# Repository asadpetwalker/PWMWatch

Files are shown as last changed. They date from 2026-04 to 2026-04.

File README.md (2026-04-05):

# PWMWatch
# What My Project Is
My project is a watch using the CrystalFontz CFAL12856A0 transparent display, the STM32WB50CGU5 mcu, and the RV3028-C7 RTC.

# Why I made my project
The electronics of watches are like really cool, and I don't see anyone actually talking about them more. I smashed a broken smart watch with a hammer, and inside there was a bunch of electronics that were really cool when I desoldered them. Additionally, the display I found, the CrystalFontz CFAL12856A0 is really cool, and I wanted to combine these two things to make a really cool watch that also focuses on the electronics.

# Pictures

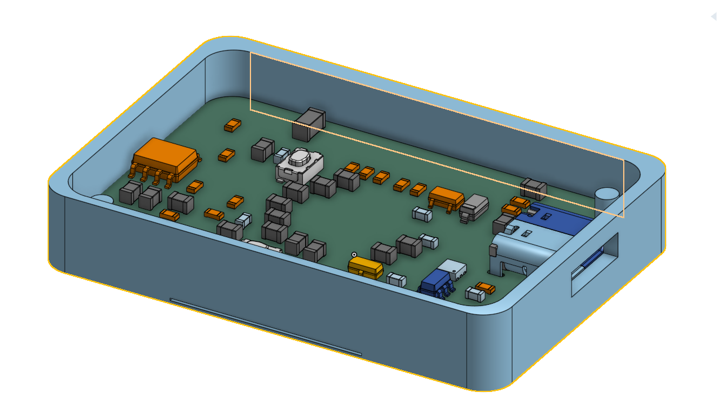
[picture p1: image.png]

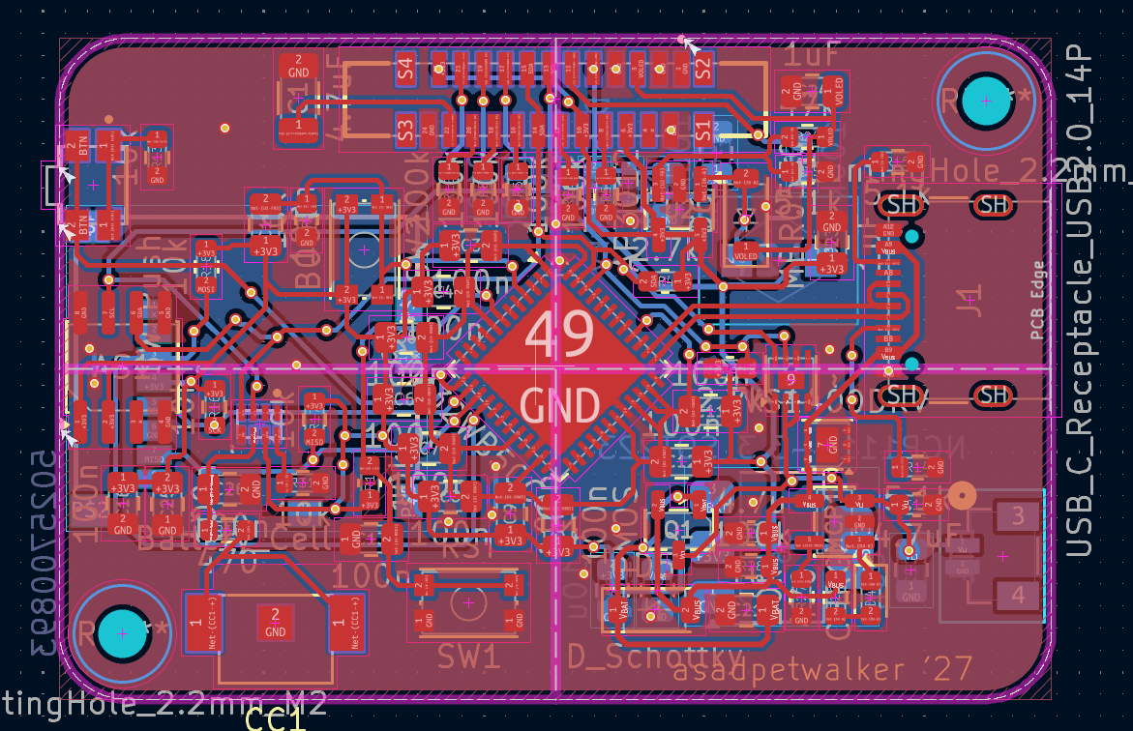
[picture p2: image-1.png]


# BOM

| Name | Purpose | Quantity | Total Cost (USD) | Link | Distributor |
|---|---|---|---|---|---|
| PCB + Stencil | PCB |  | 21.55 |  | JLCPCB |
| MBR0530TPMSCT-ND | DIODE SCHOTTKY 30V 500MA SOD123 | 2 | 0.30 | https://www.digikey.com/en/products/detail/mcc-micro-commercial-components/MBR0530-TP/717251 | Digikey |
| RB521S30T1GOSCT-ND | DIODE SCHOTTKY 30V 200MA SOD523 | 2 | 0.30 | https://www.digikey.com/en/products/detail/onsemi/RB521S30T1G/920292 | Digikey |
| B130LAW-FDICT-ND | DIODE SCHOTTKY 30V 1A SOD123 | 2 | 0.70 | https://www.digikey.com/en/products/detail/diodes-incorporated/B130LAW-7-F/725013 | Digikey |
| 36-2994-ND | BATTERY RETAINER COIN 4.8MM SMD | 2 | 0.60 | https://www.digikey.com/en/products/detail/keystone-electronics/2994/2137865 | Digikey |
| 2073-MEM2061-01-188-00-ACT-ND | CONN MICRO SD CARD R/A SMD | 2 | 2.24 | https://www.digikey.com/en/products/detail/gct/MEM2061-01-188-00-A/9859612 | Digikey |
| 108-KMR211GLFSCT-ND | SWITCH TACTILE SPST-NO 0.05A 32V | 4 | 2.44 | https://www.digikey.com/en/products/detail/c-k/KMR211G-LFS/550475 | Digikey |
| 308-1969-1-ND | FIXED IND 10UH 670MA 440 MOHM | 4 | 2.32 | https://www.digikey.com/en/products/detail/sumida-america-inc/CDRH3D14-HPNP-100NC/3946967 | Digikey |
| 311-1140-1-ND | CAP CER 0.1UF 50V X7R 0805 | 40 | 0.48 | https://www.digikey.com/en/products/detail/yageo/CC0805KRX7R9BB104/302874 | Digikey |
| 587-1441-1-ND | CAP CER 4.7UF 10V X5R 0603 | 10 | 0.20 | https://www.digikey.com/en/products/detail/taiyo-yuden/LMK107BJ475KA-T/1004029 | Digikey |
| 311-2.7KGRCT-ND | RES 2.7K OHM 5% 1/10W 0603 | 10 | 0.08 | https://www.digikey.com/en/products/detail/yageo/RC0603JR-072K7L/726735 | Digikey |
| 311-100KHRCT-ND | RES 100K OHM 1% 1/10W 0603 | 25 | 0.14 | https://www.digikey.com/en/products/detail/yageo/RC0603FR-07100KL/726889 | Digikey |
| 311-47.0KHRCT-ND | RES 47K OHM 1% 1/10W 0603 | 10 | 0.08 | https://www.digikey.com/en/products/detail/yageo/RC0603FR-0747KL/727253 | Digikey |
| 296-50511-1-ND | UNIDIR PRECISION SURGE DIODE | 3 | 2.85 | https://www.digikey.com/en/products/detail/texas-instruments/TVS1400DRVR/8566097 | Digikey |
| 2195-RV-3028-C8-32.768KHZ-1PPM-TA-QCCT-ND | IC RTC CLK/CALENDAR I2C 8SON | 1 | 3.05 | https://www.digikey.com/en/products/detail/micro-crystal-ag/RV-3028-C8-32-768KHZ-1PPM-TA-QC/26226350 | Digikey |
| AP3012KTR-G1DICT-ND | IC REG BOOST ADJ 500MA SOT23-5 | 2 | 0.58 | https://www.digikey.com/en/products/detail/diodes-incorporated/AP3012KTR-G1/4470846 | Digikey |
| MAX17048G+T10CT-ND | IC BATT MON LI-ION 1CELL 8TDFN | 1 | 4.10 | https://www.digikey.com/en/products/detail/analog-devices-inc-maxim-integrated/MAX17048G-T10/3758921 | Digikey |
| MCP73831T-2DCI/OTCT-ND | IC BATT CNTL LI-ION 1CEL SOT23-5 | 2 | 1.52 | https://www.digikey.com/en/products/detail/microchip-technology/MCP73831T-2DCI-OT/964305 | Digikey |
| AS5600-ASOTCT-ND | IC SENSOR MAG ROTARY 12BIT 8SOIC | 1 | 3.09 | https://www.digikey.com/en/products/detail/ams-osram-usa-inc/AS5600-ASOT/4914338 | Digikey |
| 3147-B1931NG--20D001114U1930CT-ND | LED GREEN DIFFUSED 0603 SMD | 2 | 0.54 | https://www.digikey.com/en/products/detail/harvatek-corporation/B1931NG-20D001114U1930/15861262 | Digikey |
| BSS83PH6327XTSA1CT-ND | MOSFET P-CH 60V 330MA SOT23-3 | 2 | 0.88 | https://www.digikey.com/en/products/detail/infineon-technologies/BSS83PH6327XTSA1/2783473 | Digikey |
| P19095CT-ND | SWITCH TACTILE SPST-NO 0.05A 12V | 4 | 1.20 | https://www.digikey.com/en/products/detail/panasonic-industry/EVQ-9P701P/5250479 | Digikey |
| 2073-USB4105-GF-ACT-ND | CONN RCP USB2.0 TYP C 16P SMD RA | 4 | 3.12 | https://www.digikey.com/en/products/detail/gct/USB4105-GF-A/11198441 | Digikey |
| 455-1788-1-ND | CONN HEADER SMD 2POS 1MM | 3 | 1.17 | https://www.digikey.com/en/products/detail/jst-sales-america-inc/BM02B-SRSS-TB/926694 | Digikey |
| 2073-FFC2A32-24-TCT-ND | CONN FFC VERT 24POS 0.5MM SMD | 4 | 2.56 | https://www.digikey.com/en/products/detail/gct/FFC2A32-24-T/10656996 | Digikey |
| 469-1075-ND | MAGNET 0.236"D X 0.098"THICK CYL | 3 | 2.25 | https://www.digikey.com/en/products/detail/radial-magnets-inc/9049/6030786 | Digikey |
| 728-1088-ND | BATTERY SLVR OX 1.55V COIN 4.8MM | 2 | 6.10 | https://www.digikey.com/en/products/detail/seiko-instruments/SR421SW/7428808 | Digikey |
| 1528-1841-ND | BATTERY LITH-ION 3.7V 500MAH | 1 | 7.95 | https://www.digikey.com/en/products/detail/adafruit-industries-llc/1578/5054539 | Digikey |
| 478-3868-1-ND | CAP TANT 4.7UF 10% 16V 1206 | 10 | 2.11 | https://www.digikey.com/en/products/detail/kyocera-avx/TAJA475K016RNJ/1126796 | Digikey |
| 587-1300-1-ND | CAP CER 10UF 10V X5R 0805 | 10 | 0.16 | https://www.digikey.com/en/products/detail/taiyo-yuden/LMK212BJ106KG-T/930652 | Digikey |
| 311-10.0KHRCT-ND | RES 10K OHM 1% 1/10W 0603 | 25 | 0.14 | https://www.digikey.com/en/products/detail/yageo/RC0603FR-0710KL/726880 | Digikey |
| 311-5.10KHRCT-ND | RES 5.1K OHM 1% 1/10W 0603 | 10 | 0.07 | https://www.digikey.com/en/products/detail/yageo/RC0603FR-075K1L/727268 | Digikey |
| 311-470GRCT-ND | RES 470 OHM 5% 1/10W 0603 | 10 | 0.07 | https://www.digikey.com/en/products/detail/yageo/RC0603JR-07470RL/726791 | Digikey |
| NCP1117LPST33T3GOSCT-ND | IC REG LINEAR 3.3V 1A SOT-223 | 2 | 0.74 | https://www.digikey.com/en/products/detail/onsemi/NCP1117LPST33T3G/2194024 | Digikey |
| 497-STM32WB50CGU5-ND | IC RF TXRX+MCU 802.15.4 48UFQFPN | 2 | 10.80 | https://www.digikey.com/en/products/detail/stmicroelectronics/STM32WB50CGU5/10673126 | Digikey |

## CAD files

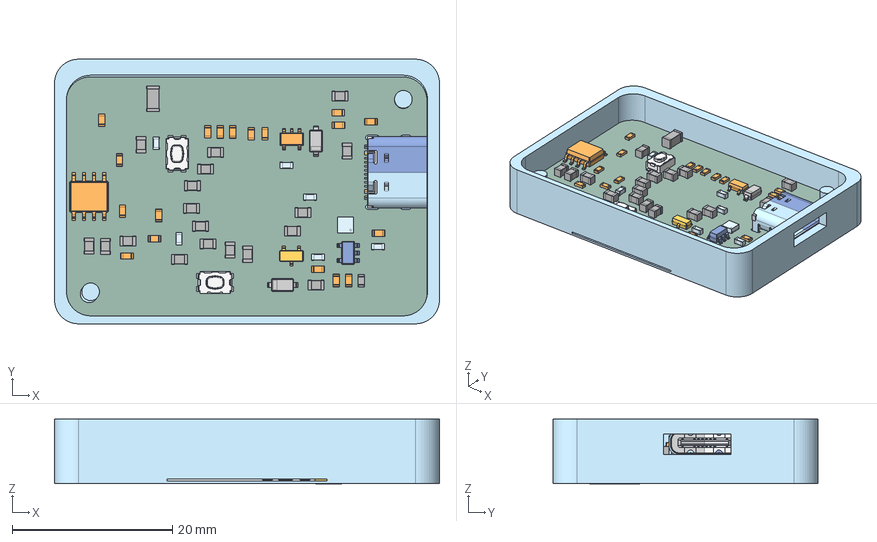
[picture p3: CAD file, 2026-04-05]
pcb 1.step
48.0 x 33.0 x 8.04 mm
USB_C_Receptacle_GCT_USB4105-xx-A_16P_TopMnt_Horizontal x 36
C_0603_1608Metric x 6
R_0603_1608Metric x 23
C_0805_2012Metric x 23
SOT-223
C_1206_3216Metric
SC-74A-5_1.55x2.9mm_P0.95mm
D_SOD-523
LED_0603_1608Metric
SW_Push_1P1T_NO_CK_KMR2 x 2
D_SOD-123 x 2
SOT-23-3
PWMWatch_PCB
WSON-6-1EP_2x2mm_P0.65mm_EP1x1.6mm
SOT-23-5
SOIC-8_3.9x4.9mm_P1.27mm

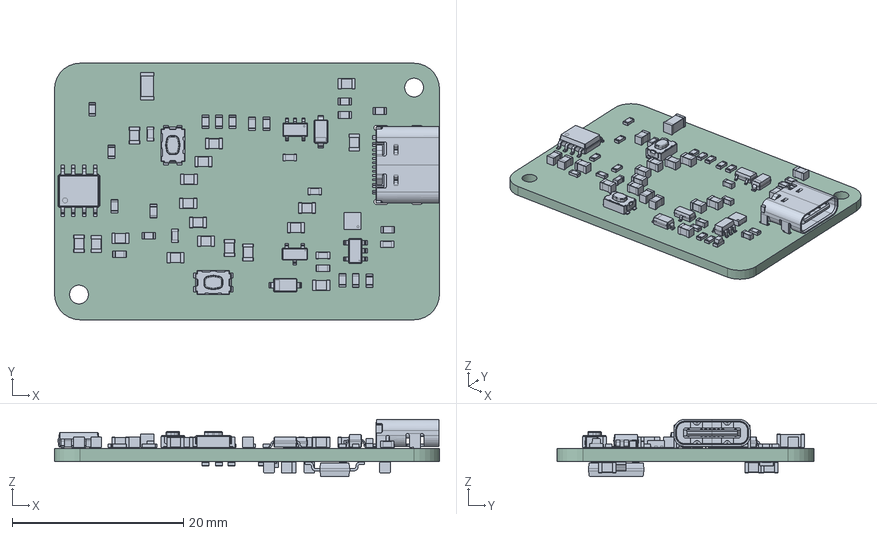
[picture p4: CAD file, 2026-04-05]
PWMWatch/pcb.step
45.0 x 30.0 x 6.69 mm
LED_0603_1608Metric
R_0603_1608Metric x 23
C_0805_2012Metric x 23
SC-74A-5_1.55x2.9mm_P0.95mm
WSON-6-1EP_2x2mm_P0.65mm_EP1x1.6mm
USB_C_Receptacle_GCT_USB4105-xx-A_16P_TopMnt_Horizontal
C_0603_1608Metric x 6
D_SOD-123 x 2
SOT-23-3
C_1206_3216Metric
SW_Push_1P1T_NO_CK_KMR2 x 2
SOIC-8_3.9x4.9mm_P1.27mm
SOT-23-5
D_SOD-523
SOT-223
PWMWatch_PCB

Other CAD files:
PWMWatch/.step

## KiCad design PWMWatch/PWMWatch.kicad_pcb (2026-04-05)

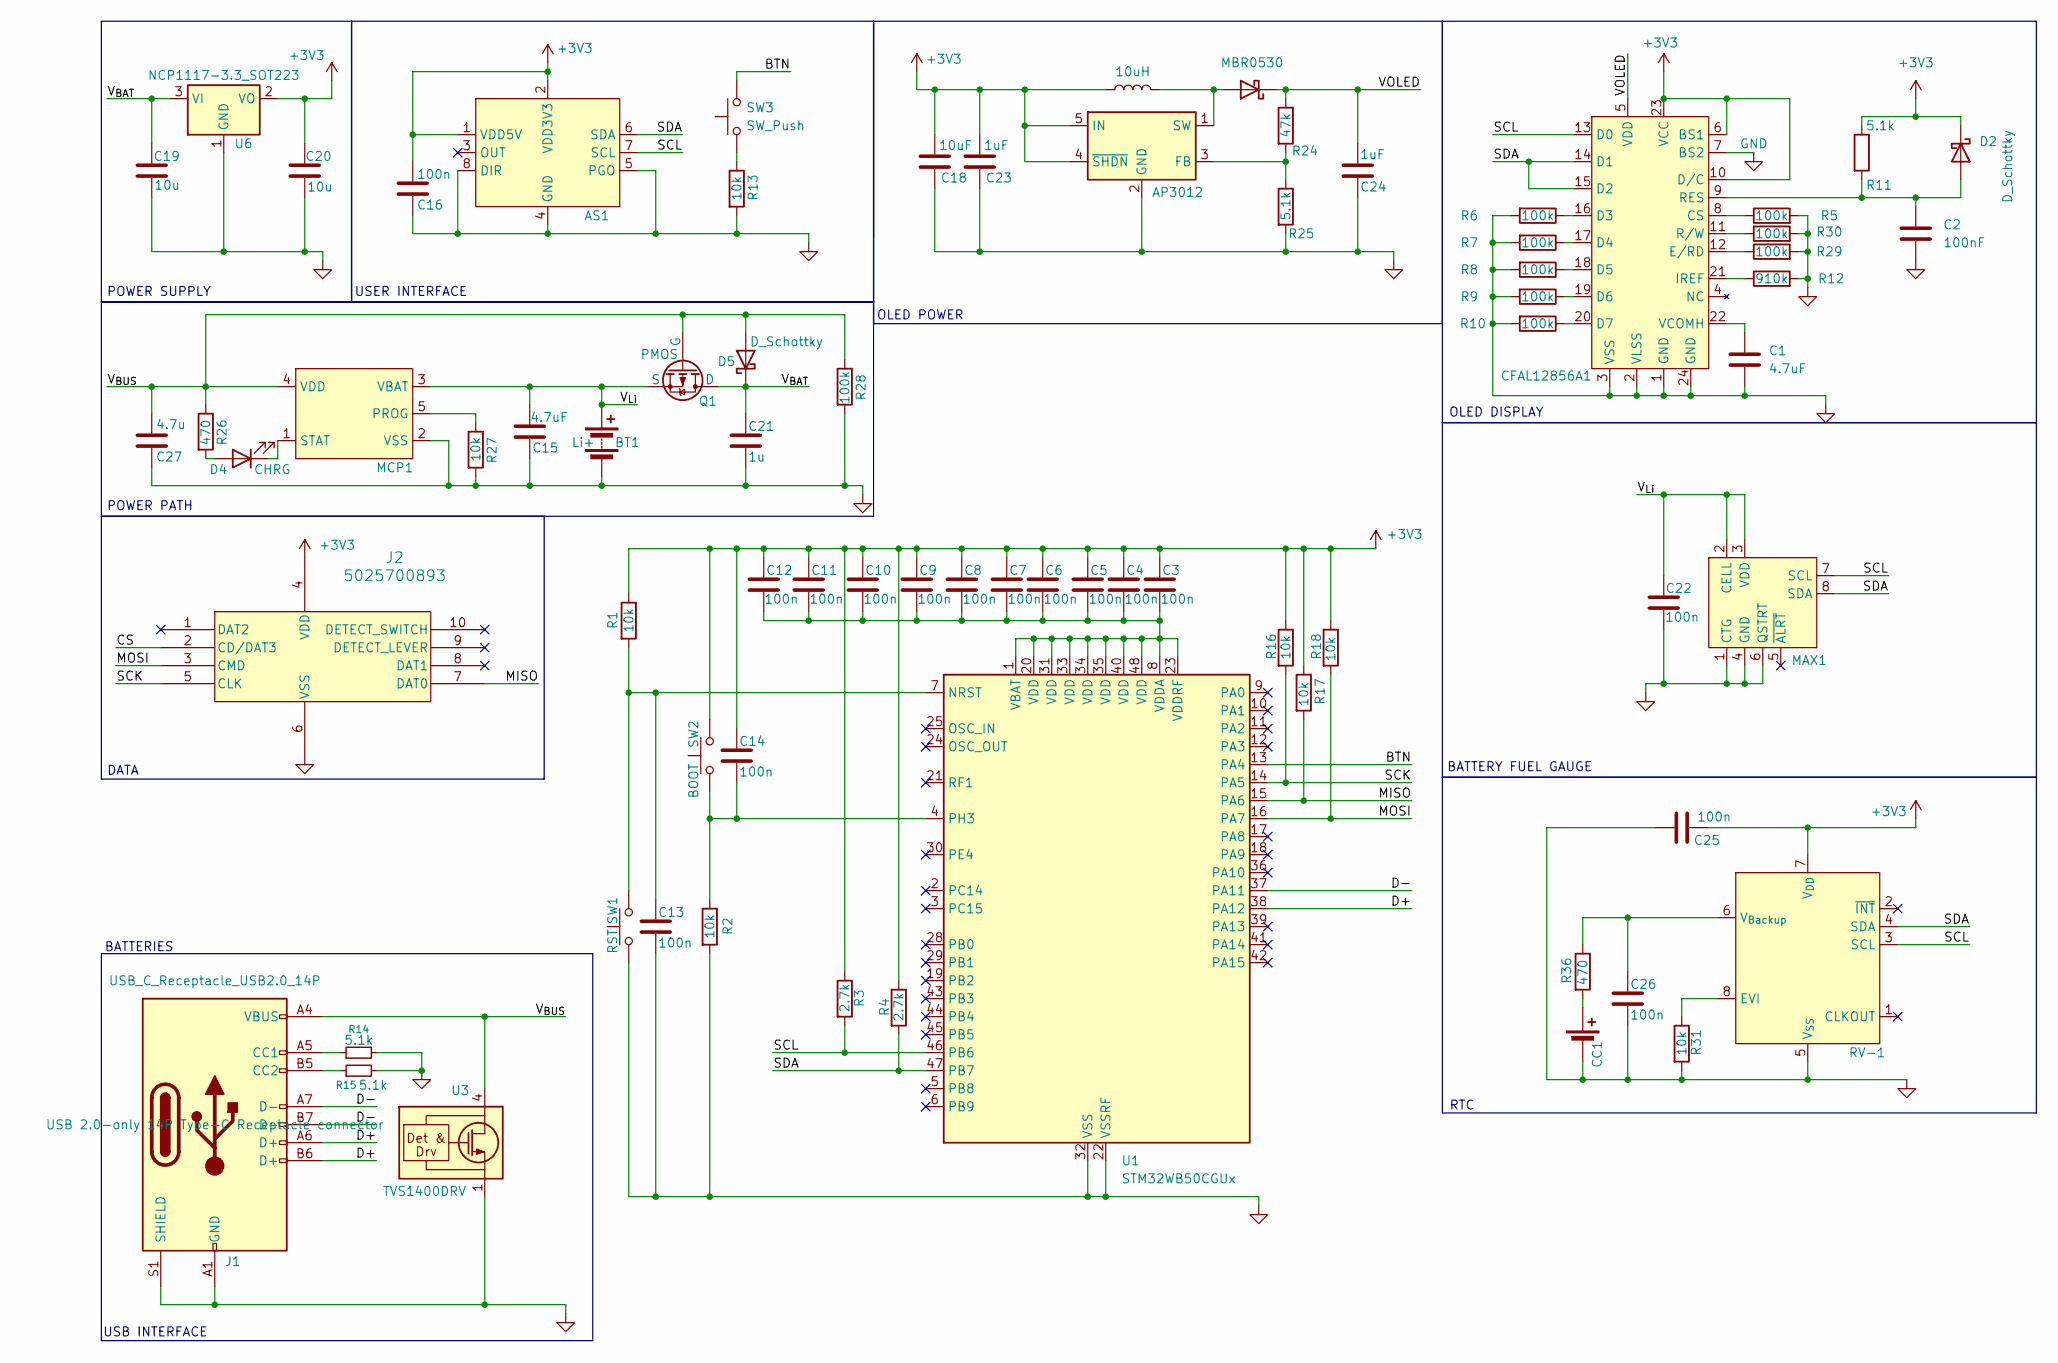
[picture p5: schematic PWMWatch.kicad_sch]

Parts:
AS1: SOIC-8_3.9x4.9mm_P1.27mm
BT1: Li+; CONN_BM02B-SRSS-TB_JST
C1: 4.7uF; C_1206_3216Metric
C2: 100nF; C_0805_2012Metric
C3, C4, C5, C6, C7, C8, C9, C10, C11, C12, C13, C14, C16, C22, C25, C26: 100n; C_0805_2012Metric
C15: 4.7uF; C_0603_1608Metric
C18: 10uF; C_0805_2012Metric
C19, C20: 10u; C_0805_2012Metric
C21: 1u; C_0805_2012Metric
C23, C24: 1uF; C_0805_2012Metric
C27: 4.7u; C_0603_1608Metric
CC1: Battery_Cell; BAT_2994
CFAL12856A1: GCT_FFC2A32-24-T
D2: D_Schottky; D_SOD-523
D4: CHRG; LED_0603_1608Metric
D5: D_Schottky; D_SOD-123
D6: MBR0530; D_SOD-123
J1: USB_C_Receptacle_USB2.0_14P; USB_C_Receptacle_GCT_USB4105-xx-A_16P_TopMnt_Horizontal
J2: 5025700893; MOLEX_5025700893
L2: 10uH; CDRH3D14HPNP100NC
MAX1: TDFN-8-1EP_2x2mm_P0.5mm_EP0.8x1.2mm
MCP1: SOT-23-5
Q1: PMOS; SOT-23-3
R1, R2: 10k; C_0603_1608Metric
R3, R4: 2.7k; C_0603_1608Metric
R5, R6, R7, R8, R9, R10, R28, R29, R30: 100k; R_0603_1608Metric
R11, R14, R15, R25: 5.1k; R_0603_1608Metric
R12: 910k; R_0603_1608Metric
R13, R16, R17, R18, R27, R31: 10k; R_0603_1608Metric
R24: 47k; R_0603_1608Metric
R26, R36: 470; R_0603_1608Metric
RV-1: IC_RV-3028-C8-32.768KHZ-1PPM-TA-QC
SW1: RST; SW_Push_1P1T_NO_CK_KMR2
SW2: BOOT; SW_Push_1P1T_NO_CK_KMR2
SW3: SW_Push; SW_EVQ-P7A01P
U1: STM32WB50CGUx; QFN-48-1EP_7x7mm_P0.5mm_EP5.6x5.6mm
U2: AP3012; SC-74A-5_1.55x2.9mm_P0.95mm
U3: TVS1400DRV; WSON-6-1EP_2x2mm_P0.65mm_EP1x1.6mm
U6: NCP1117-3.3_SOT223; SOT-223-3_TabPin2

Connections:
+3V3: AS1.1 (VDD5V), AS1.2 (VDD3V3), C3.1, C4.1, C5.1, C6.1, C7.1, C8.1, C9.1, C10.1, C11.1, C12.1, C14.1, C16.1, C18.1, C20.2, C23.1, C25.2, CFAL12856A1.6 (BS1), CFAL12856A1.10 (D/C), CFAL12856A1.23 (VCC), D2.1 (K), J2.4 (VDD), L2.1, R1.1, R3.1, R4.1, R11.1, R16.1, R17.1, R18.1, RV-1.7 (V_{DD}), SW2.2, U2.4 (~SHDN), U2.5 (IN), U6.2 (VO)
/BTN: SW3.2, U1.13 (PA4)
/CS: J2.2 (CD/DAT3)
/D+: J1.A6 (D+), J1.B6 (D+), U1.38 (PA12)
/D-: J1.A7 (D-), J1.B7 (D-), U1.37 (PA11)
/MISO: J2.7 (DAT0), R17.2, U1.15 (PA6)
/MOSI: J2.3 (CMD), R18.2, U1.16 (PA7)
/SCK: J2.5 (CLK), R16.2, U1.14 (PA5)
/SCL: AS1.7 (SCL), CFAL12856A1.13 (D0), MAX1.7 (SCL), R3.2, RV-1.3 (SCL), U1.46 (PB6)
/SDA: AS1.6 (SDA), CFAL12856A1.14 (D1), CFAL12856A1.15 (D2), MAX1.8 (SDA), R4.2, RV-1.4 (SDA), U1.47 (PB7)
/VOLED: C24.1, CFAL12856A1.5 (VDD), D6.1 (K), R24.1
/V_{BAT}: C19.2, C21.1, D5.1 (K), Q1.1 (D), U6.3 (VI)
/V_{BUS}: C27.1, D5.2 (A), J1.A4 (VBUS), J1.A9 (VBUS), J1.B4 (VBUS), J1.B9 (VBUS), MCP1.4 (VDD), Q1.2 (G), R26.1, R28.1, U3.4 (IN), U3.5 (IN), U3.6 (IN)
/V_{Li}: BT1.1 (+), C15.1, C22.2, MAX1.2 (CELL), MAX1.3 (VDD), MCP1.3 (VBAT), Q1.3 (S)
GND: AS1.4 (GND), AS1.5 (PGO), AS1.8 (DIR), BT1.2 (-), C1.2, C2.2, C13.1, C15.2, C16.2, C18.2, C19.1, C20.1, C21.2, C22.1, C23.2, C24.2, C25.1, C26.2, C27.2, CC1.2 (-), CFAL12856A1.1 (GND), CFAL12856A1.2 (VLSS), CFAL12856A1.3 (VSS), CFAL12856A1.7 (BS2), CFAL12856A1.24 (GND), J1.A1 (GND), J1.A12 (GND), J1.B1 (GND), J1.B12 (GND), J1.S1 (SHIELD), J2.6 (VSS), MAX1.1 (CTG), MAX1.4 (GND), MAX1.6 (QSTRT), MCP1.2 (VSS), R2.2, R5.2, R6.2, R7.2, R8.2, R9.2, R10.2, R12.2, R13.2, R14.2, R15.2, R25.2, R27.2, R28.2, R29.2, R30.2, R31.2, RV-1.5 (V_{SS}), SW1.1, U1.22 (VSSRF), U1.32 (VSS), U1.49 (VSS), U2.2 (GND), U3.1 (GND), U3.2 (GND), U3.3 (GND), U3.7 (GND), U6.1 (GND)
unnamed: CC1.1 (+), R36.2
unnamed: CFAL12856A1.8 (CS), R5.1
unnamed: CFAL12856A1.16 (D3), R6.1
unnamed: CFAL12856A1.17 (D4), R7.1
unnamed: CFAL12856A1.18 (D5), R8.1
unnamed: CFAL12856A1.19 (D6), R9.1
unnamed: CFAL12856A1.20 (D7), R10.1
unnamed: CFAL12856A1.12 (E/RD), R29.1
unnamed: CFAL12856A1.21 (IREF), R12.1
unnamed: C2.1, CFAL12856A1.9 (RES), D2.2 (A), R11.2
unnamed: CFAL12856A1.11 (R/W), R30.1
unnamed: C1.1, CFAL12856A1.22 (VCOMH)
unnamed: D4.2 (A), R26.2
unnamed: D4.1 (K), MCP1.1 (STAT)
unnamed: D6.2 (A), L2.2, U2.1 (SW)
unnamed: J1.A5 (CC1), R14.1
unnamed: J1.B5 (CC2), R15.1
unnamed: MCP1.5 (PROG), R27.1
unnamed: R13.1, SW3.1
unnamed: R31.1, RV-1.8 (EVI)
unnamed: C26.1, R36.1, RV-1.6 (V_{Backup})
unnamed: C13.2, R1.2, SW1.2, U1.7 (NRST)
unnamed: C14.2, R2.1, SW2.1, U1.4 (PH3)
unnamed: C3.2, C4.2, C5.2, C6.2, C7.2, C8.2, C9.2, C10.2, C11.2, C12.2, U1.1 (VBAT), U1.8 (VDDA), U1.20 (VDD), U1.23 (VDDRF), U1.31 (VDD), U1.33 (VDD), U1.34 (VDD), U1.35 (VDD), U1.40 (VDD), U1.48 (VDD)
unnamed: R24.2, R25.1, U2.3 (FB)

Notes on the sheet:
OLED POWER
POWER SUPPLY
RTC
POWER PATH
USB INTERFACE
BATTERY FUEL GAUGE
DATA
BATTERIES
USER INTERFACE
OLED DISPLAY

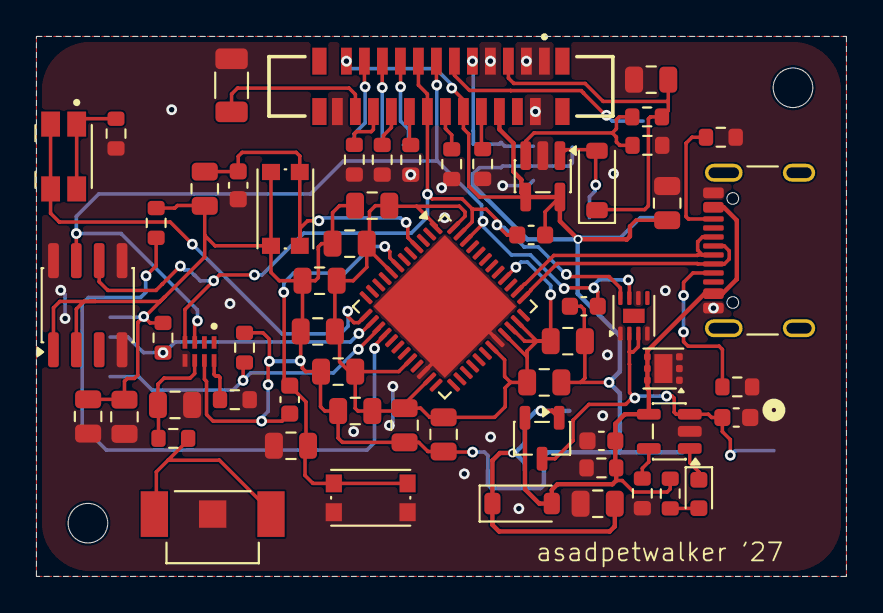
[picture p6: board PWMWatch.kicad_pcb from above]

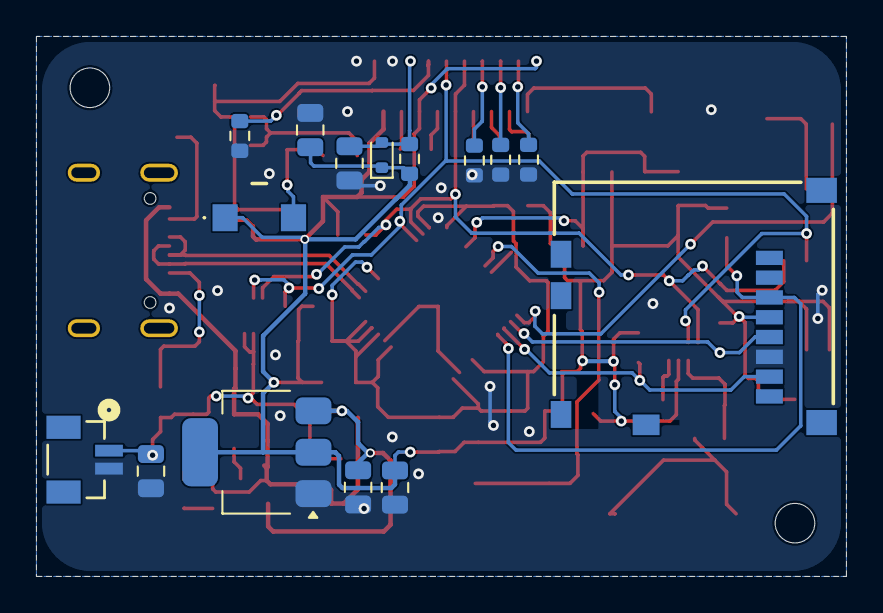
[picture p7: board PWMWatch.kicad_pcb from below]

Board: 2 copper layers, 45.0 x 30.0 mm, 75 parts (15 on the bottom side), 39 nets.

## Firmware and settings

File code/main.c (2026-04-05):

/* ============================================================
 * Watch firmware - STM32WB50CGU5
 * Display : CFAL12856A0 (SSD1309, 128x56) on I2C1
 * RTC     : RV3028-C7 on I2C1
 * I2C1    : PB8 = SCL (pin 46), PB9 = SDA (pin 47)
 *
 * Reads HH:MM:SS from the RV3028 every second and
 * renders it centred on the OLED using a large 5x7 font
 * scaled 3x for readability on a watch face.
 * ============================================================ */

#include "main.h"
#include "i2c.h"
#include "ssd1309.h"
#include "rv3028.h"
#include "font.h"

/* Update interval - check RTC every 500 ms so display
 * never lags more than half a second behind real time  */
#define UPDATE_INTERVAL_MS  500

int main(void)
{
    HAL_Init();
    SystemClock_Config();

    /* I2C1 on PB8/PB9, 400 kHz fast mode */
    MX_I2C1_Init();

    /* Bring up display */
    SSD1309_Init();
    SSD1309_Clear();

    /* Optional: set initial time if the RTC has never been
     * programmed. Comment out after first flash.          */
    /* RV3028_SetTime(12, 0, 0); */

    uint32_t last_tick = 0;

    while (1)
    {
        uint32_t now = HAL_GetTick();
        if ((now - last_tick) >= UPDATE_INTERVAL_MS)
        {
            last_tick = now;

            uint8_t hours, minutes, seconds;
            RV3028_GetTime(&hours, &minutes, &seconds);

            SSD1309_Clear();
            SSD1309_DrawTime(hours, minutes, seconds);
            SSD1309_Flush();
        }

        /* Sleep until next systick to save power */
        __WFI();
    }
}

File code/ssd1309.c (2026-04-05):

/* ============================================================
 * SSD1309 OLED driver
 * 128 x 56 pixels, I2C, for CFAL12856A0-0151-B
 *
 * The SSD1309 has 8 pages of 8 rows each (= 64 rows total).
 * The CFAL12856A0 exposes only the top 56 rows; the bottom
 * 8 rows are behind the getter and not visible. We simply
 * never write to page 6 (rows 48-55 of controller space) or
 * page 7 (rows 56-63). Keeping HEIGHT=56 handles this.
 *
 * Framebuffer layout: [page][column]
 *   pages 0-6 = rows 0-55  (7 pages x 128 cols = 896 bytes)
 * ============================================================ */

#include "ssd1309.h"
#include "i2c.h"
#include <string.h>

/* Number of pages actually used for 56 visible rows */
#define SSD1309_PAGES   ((SSD1309_HEIGHT + 7) / 8)   /* = 7 */

/* Local framebuffer - one byte per column per page */
static uint8_t framebuf[SSD1309_PAGES][SSD1309_WIDTH];

/* ---- internal helpers ---------------------------------------- */

extern I2C_HandleTypeDef hi2c1;

static void send_cmd(uint8_t cmd)
{
    uint8_t buf[2] = { SSD1309_CTRL_CMD, cmd };
    HAL_I2C_Master_Transmit(&hi2c1, SSD1309_I2C_ADDR,
                             buf, 2, HAL_MAX_DELAY);
}

static void send_cmd2(uint8_t cmd, uint8_t arg)
{
    uint8_t buf[3] = { SSD1309_CTRL_CMD, cmd, arg };
    HAL_I2C_Master_Transmit(&hi2c1, SSD1309_I2C_ADDR,
                             buf, 3, HAL_MAX_DELAY);
}

/* ---- public API --------------------------------------------- */

void SSD1309_Init(void)
{
    /* Reset sequence recommended by SSD1309 datasheet and the
     * Crystalfontz CFAL12856A0 application note.              */
    HAL_Delay(10);

    send_cmd(0xAE);         /* display off                      */

    send_cmd2(0xD5, 0x80);  /* clock divide / osc freq          */
    send_cmd2(0xA8, 0x3F);  /* multiplex ratio: 64 MUX          */
    send_cmd2(0xD3, 0x00);  /* display offset: 0                */
    send_cmd(0x40);         /* display start line = 0           */

    send_cmd2(0x8D, 0x14);  /* charge pump: enable              */

    send_cmd2(0x20, 0x00);  /* horizontal addressing mode       */

    send_cmd(0xA1);         /* segment remap: col 127 = SEG0    */
    send_cmd(0xC8);         /* COM scan direction: remapped     */

    send_cmd2(0xDA, 0x12);  /* COM pin config: alt, no remap    */
    send_cmd2(0x81, 0xCF);  /* contrast                         */
    send_cmd2(0xD9, 0xF1);  /* pre-charge period                */
    send_cmd2(0xDB, 0x40);  /* VCOMH deselect level             */

    send_cmd(0xA4);         /* entire display on: follow RAM    */
    send_cmd(0xA6);         /* normal display (not inverted)    */
    send_cmd(0xAF);         /* display on                       */

    SSD1309_Clear();
    SSD1309_Flush();
}

void SSD1309_Clear(void)
{
    memset(framebuf, 0, sizeof(framebuf));
}

void SSD1309_Flush(void)
{
    /* Set column and page address window to full display */
    send_cmd(0x21);   /* set column address... */
    send_cmd(0);      /* start = 0             */
    send_cmd(SSD1309_WIDTH - 1); /* end = 127  */

    send_cmd(0x22);   /* set page address...   */
    send_cmd(0);      /* start page = 0        */
    send_cmd(SSD1309_PAGES - 1); /* end page   */

    /* Stream all framebuffer data in one I2C transaction.
     * Max HAL transmit buffer is typically fine for 896+1 bytes
     * but we send page by page to stay safe on all HAL configs. */
    for (uint8_t page = 0; page < SSD1309_PAGES; page++)
    {
        /* Prepend the control byte for GDDRAM data */
        uint8_t txbuf[SSD1309_WIDTH + 1];
        txbuf[0] = SSD1309_CTRL_DATA;
        memcpy(&txbuf[1], framebuf[page], SSD1309_WIDTH);
        HAL_I2C_Master_Transmit(&hi2c1, SSD1309_I2C_ADDR,
                                 txbuf, sizeof(txbuf),
                                 HAL_MAX_DELAY);
    }
}

void SSD1309_SetPixel(int16_t x, int16_t y, uint8_t on)
{
    if (x < 0 || x >= SSD1309_WIDTH ||
        y < 0 || y >= SSD1309_HEIGHT) return;

    uint8_t page = (uint8_t)(y / 8);
    uint8_t bit  = (uint8_t)(y % 8);

    if (on)
        framebuf[page][x] |=  (1 << bit);
    else
        framebuf[page][x] &= ~(1 << bit);
}

/* ---- time rendering ----------------------------------------- */

/* Forward declaration of font helpers defined in font.c */
extern const uint8_t font5x7[][5];
void SSD1309_DrawChar(int16_t x, int16_t y,
                      char c, uint8_t scale);
void SSD1309_DrawString(int16_t x, int16_t y,
                        const char *str, uint8_t scale);

/*
 * SSD1309_DrawTime
 *
 * Renders "HH:MM:SS" centred horizontally and vertically.
 *
 * With scale=3 each character is 15 px wide (5*3) and
 * 21 px tall (7*3), with 3 px gap between chars.
 *
 * "HH:MM:SS" = 8 chars + 2 colons = 8 chars total in the
 * string. Width = 8*(15+3) - 3 = 141 px  -- slightly too
 * wide for 128 px at scale 3.
 *
 * So we use scale=3 for HH:MM and put :SS smaller (scale=2)
 * below, giving a clean watch layout:
 *
 *   [        HH:MM        ]   y = 4,  scale 3, 21 px tall
 *   [          :SS        ]   y = 32, scale 2, 14 px tall
 *
 * Total height = 4 + 21 + 4 + 14 = 43, centred in 56 rows.
 */
void SSD1309_DrawTime(uint8_t hours, uint8_t minutes,
                      uint8_t seconds)
{
    char hhmm[6], ss[4];

    /* Format strings */
    hhmm[0] = '0' + (hours   / 10);
    hhmm[1] = '0' + (hours   % 10);
    hhmm[2] = ':';
    hhmm[3] = '0' + (minutes / 10);
    hhmm[4] = '0' + (minutes % 10);
    hhmm[5] = '\0';

    ss[0] = ':';
    ss[1] = '0' + (seconds / 10);
    ss[2] = '0' + (seconds % 10);
    ss[3] = '\0';

    /* Scale 3: char cell = (5*3 + 3) = 18 px wide, 5 chars */
    /* "HH:MM" = 5 chars => 5*18 - 3 = 87 px wide           */
    uint8_t scale_hhmm = 3;
    uint8_t char_w_hhmm = 5 * scale_hhmm + scale_hhmm; /* 18 */
    int16_t total_w_hhmm = 5 * char_w_hhmm - scale_hhmm; /* 87 */
    int16_t x_hhmm = (SSD1309_WIDTH - total_w_hhmm) / 2;
    int16_t y_hhmm = 4;

    /* Scale 2: char cell = (5*2 + 2) = 12 px wide, 3 chars */
    /* ":SS" = 3 chars => 3*12 - 2 = 34 px wide             */
    uint8_t scale_ss = 2;
    uint8_t char_w_ss = 5 * scale_ss + scale_ss;  /* 12 */
    int16_t total_w_ss = 3 * char_w_ss - scale_ss; /* 34 */
    int16_t x_ss = (SSD1309_WIDTH - total_w_ss) / 2;
    int16_t y_ss = y_hhmm + 7 * scale_hhmm + 4;  /* 4 + 21 + 4 = 29 */

    SSD1309_DrawString(x_hhmm, y_hhmm, hhmm, scale_hhmm);
    SSD1309_DrawString(x_ss,   y_ss,   ss,   scale_ss);
}
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

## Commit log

2026-03-05 Started schematic
    [PWMWatch.kicad_pcb, PWMWatch.kicad_sch]
2026-03-06 Added RTC
    [PWMWatch.kicad_sch]
2026-03-21 magnetic encoder + buttons + organization of schematic
    [PWMWatch.kicad_sch]
2026-03-24 placements + fixed all the wrong footprints
    [PWMWatch.kicad_pcb, PWMWatch.kicad_sch]
2026-04-02 pcb done 4th time
    [PWMWatch.kicad_pcb, PWMWatch.kicad_sch]
2026-04-05 all the stuff done
    [.step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]
2026-04-05 readme + csv
    [bom.csv, pcb 1.step]
